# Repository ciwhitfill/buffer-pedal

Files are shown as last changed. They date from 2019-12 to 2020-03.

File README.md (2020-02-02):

# JFET Buffer

This project documents the design and construction of a JFET buffer guitar pedal.

## BOM
|Quantity |Designators |Description |Value |Package |Mouser Part # |
|:---|:---|:---|:---|:---|:---|
|3 |R1, R2, R3  |Resistor |10Mohm, 1/8W  |3.6mm |594-5063JD10M00FT |
|1 |R 5 |Resistor |330ohms, 1/8W |3.6mm |603-MFR-12FTF52-330R|
|1 |R6 |Resistor |100Kohms, 1/8W|3.6mm |603-CFR-12JT-52-100K|
|1 |R7 |Resistor |4.7Kohms, 1/8W|3.6mm |603-MFR-12FTF52-4K7 |
|2 |C1, C2 |Capacitor, polarized|10uF, 16V |4mm |647-USW1C100MDD |
|1 |C3 |Capacitor, polarized|47uF, 25V |5mm |647-UFW1E470MDD |
|2 |Q1, Q2 |N-Channel JFET |J113 |TO-92 |512-J113 |
|1 |D1 |Diode |1N4003 |DO-41 |583-1N4003-T |
|1 |D2 |LED |Green |5mm |859-LTL2R3KGD-EM |
|2 |J1, J2 |Phone Connector |1/4" TS | |568-NYS229 |
|1 |J3 |DC Power Connector  |2.1mm | |163-1060-EX |

## Design

The circuit consists of a JFET source follower with an active load. Compared to passive biasing, an active load provides an operating point that is stable over a much larger range of voltages. This allows the amplifier to drive lower impedance loads at lower supply voltages.

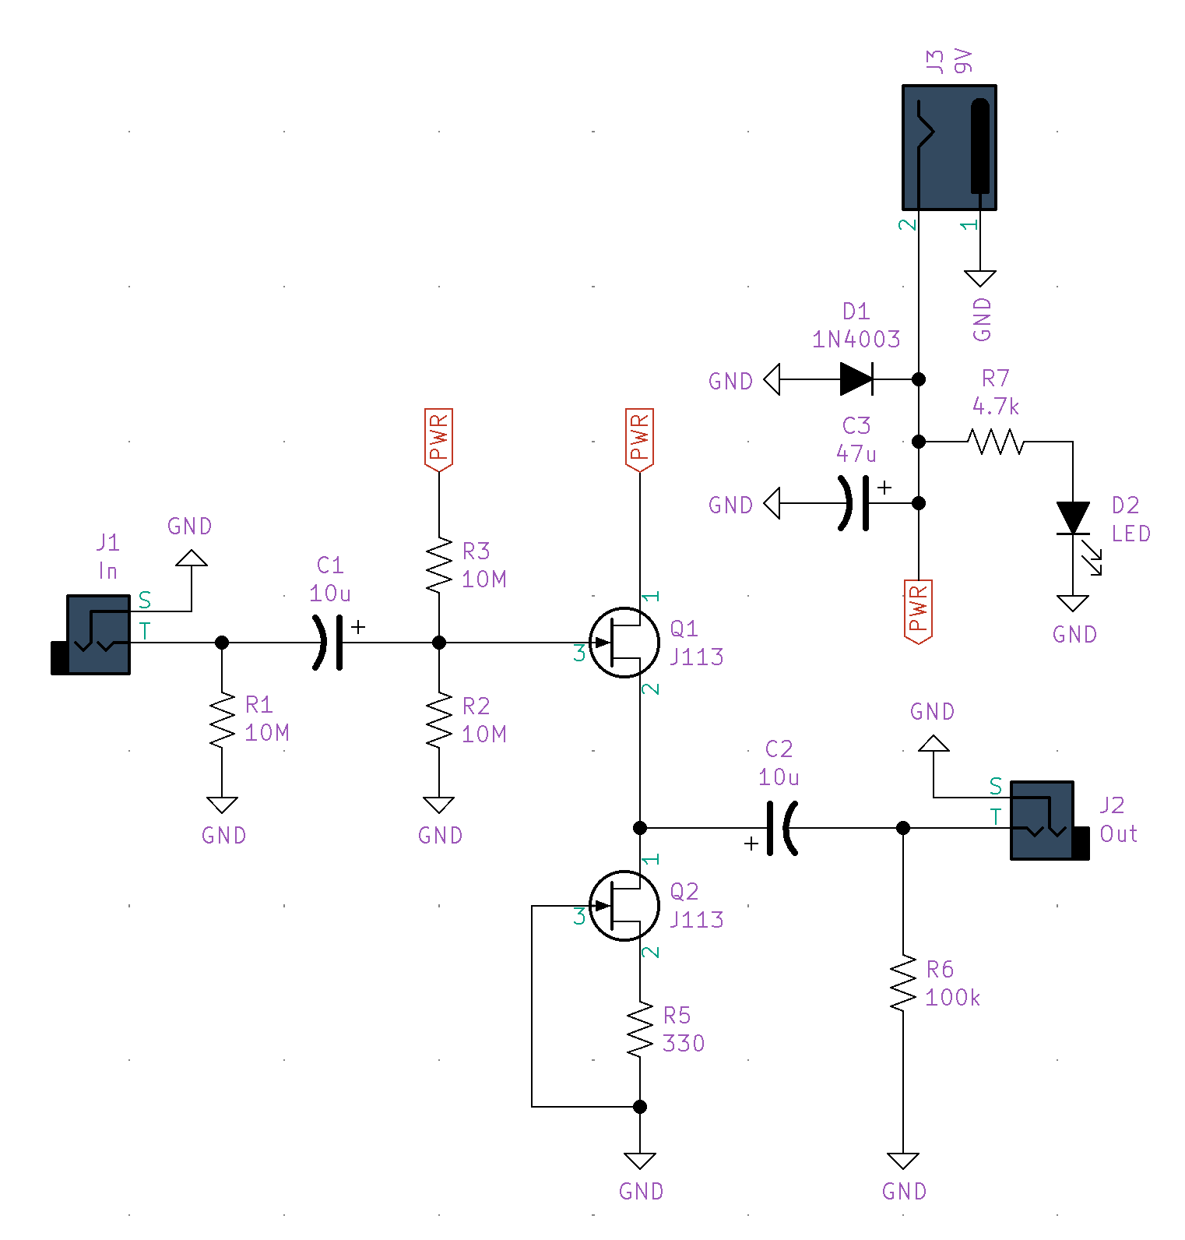
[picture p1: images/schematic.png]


## Simulation Results
The following simulations were conducted in LTspice. For the schematic file and simulation results, [see the simulation folder.](./simulation)

### Input Impedance 
A high input impedance is necessary to avoid loading passive guitar pickups. Generally, an input impedance of at least 1 MΩ is desired. The design provides this impedance throughout the audio range.

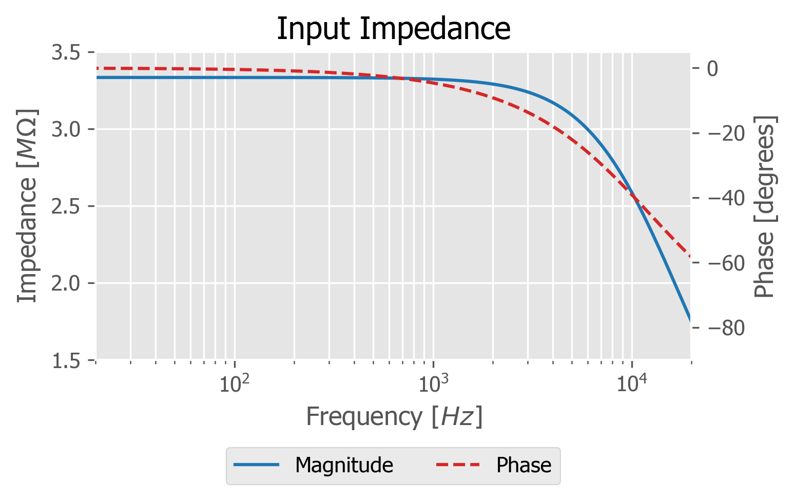
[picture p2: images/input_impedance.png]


### Output Impedance
The design provides a low enough output impedance to drive line-level inputs. While the coupling capacitor dominates at low frequencies, the output impedance asymptotes to 100 Ω, which is more than sufficient for instrument level applications.

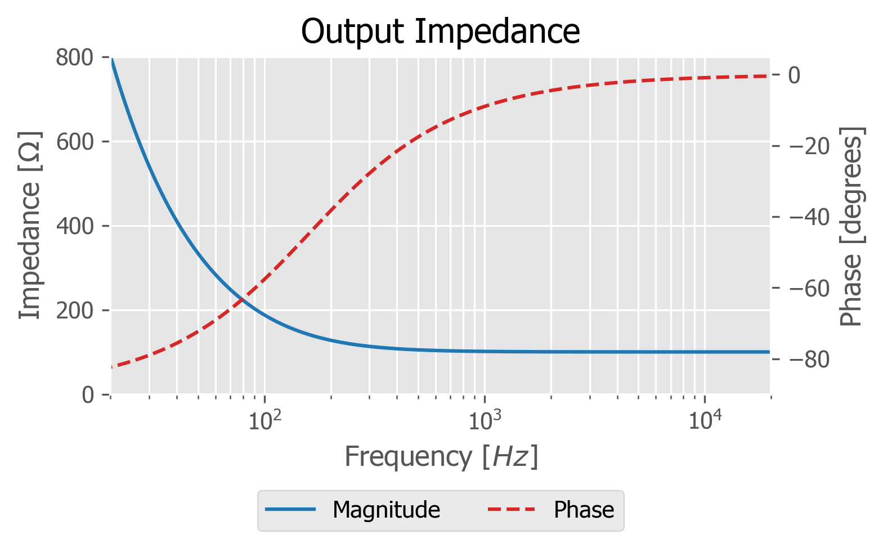
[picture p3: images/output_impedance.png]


### Gain
A good voltage buffer has as close to a gain of 1 as possible. Due to the higher impedance of the active load, the design comes within 0.1 dB of this.

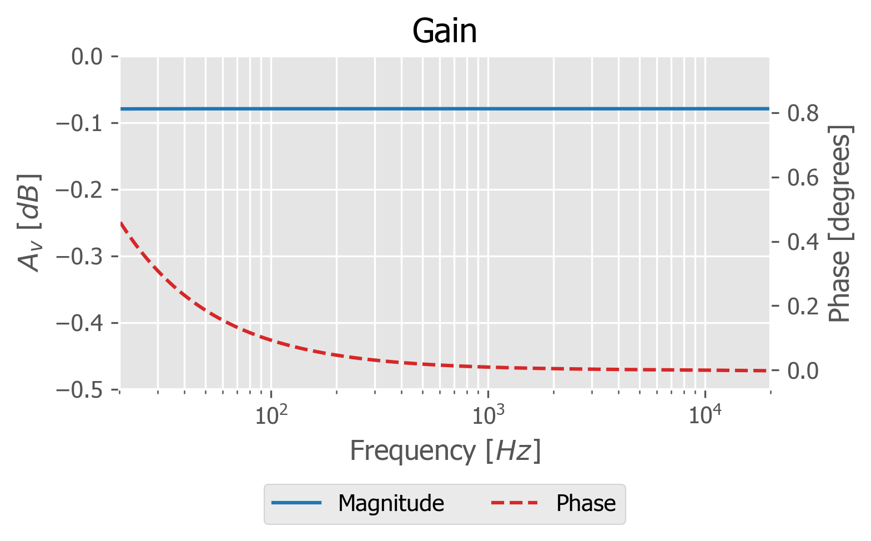
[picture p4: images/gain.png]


### Power Supply Rejection
The design has a PSRR of -43dB at DC, and the power supply capacitor further filters supply noise at high frequencies.

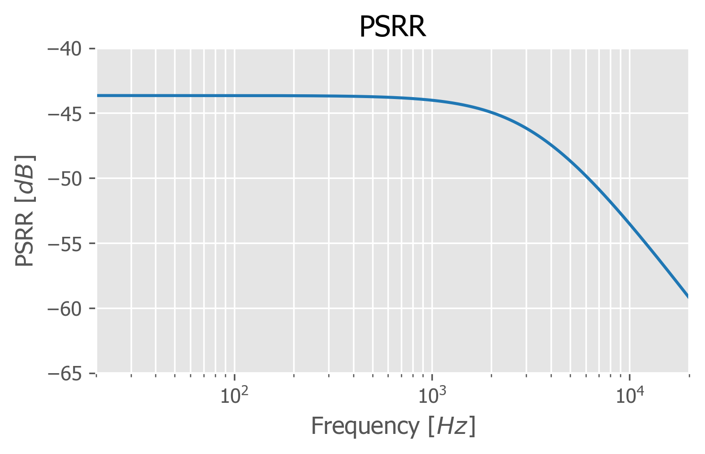
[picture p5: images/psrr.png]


### Noise
Noise simulation results in 171.18 nV in the audio range. Even if actual circuit noise is many times worse, it will be negligible compared to other noise sources in the signal chain.

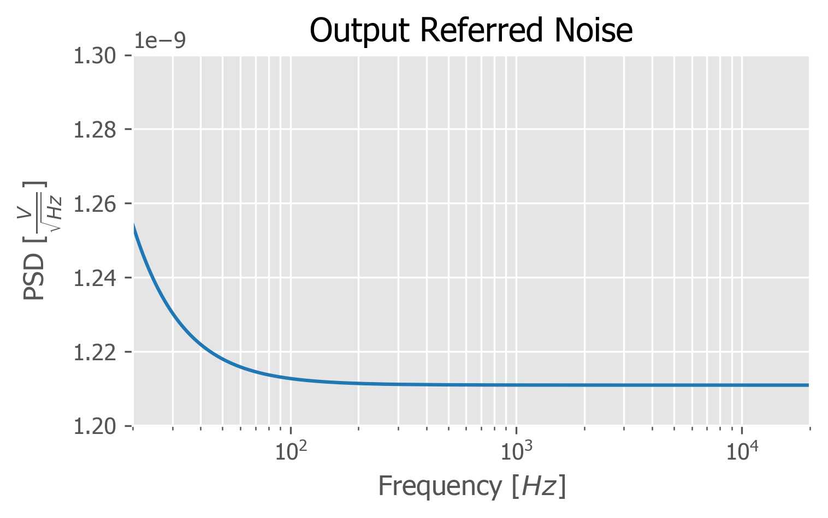
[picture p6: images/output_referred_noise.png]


## Testing

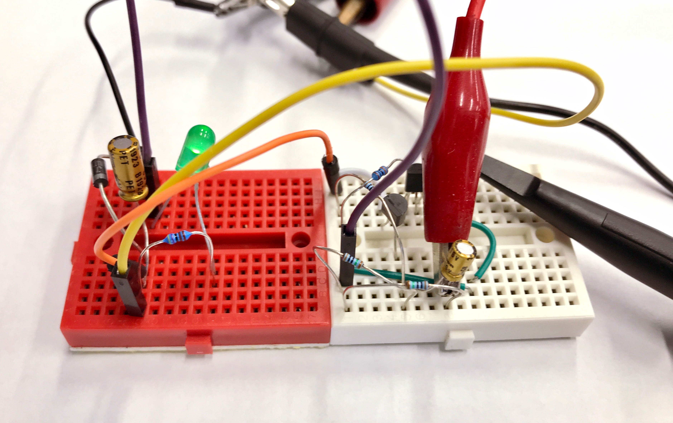
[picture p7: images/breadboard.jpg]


When a 1 V, 1 kHz test signal is applied to the input, the buffer reproduces it at the output within the precision of the test equipment available.

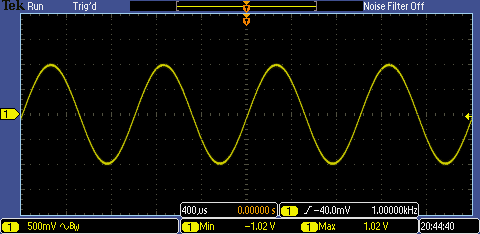
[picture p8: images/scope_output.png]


When overdriven, the buffer clips asymmetically, resulting in predominantly 2nd-order harmonic distortion. In guitar circuits, this is generally preferred to the odd-order distortion of amplifiers with high loop gain.

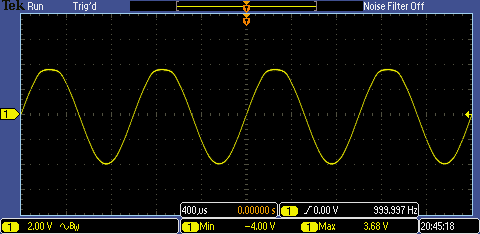
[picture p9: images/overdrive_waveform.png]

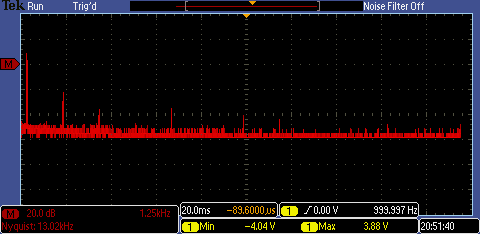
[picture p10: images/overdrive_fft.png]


### Frequency Response
In practice, the amplifier exhibits mild roll-off of sub-bass frequencies below 30 Hz. This is well below the necessary bandwidth of a guitar amplifier. The high-end frequency response extends well above the audio band, ensuring accurate phase response.

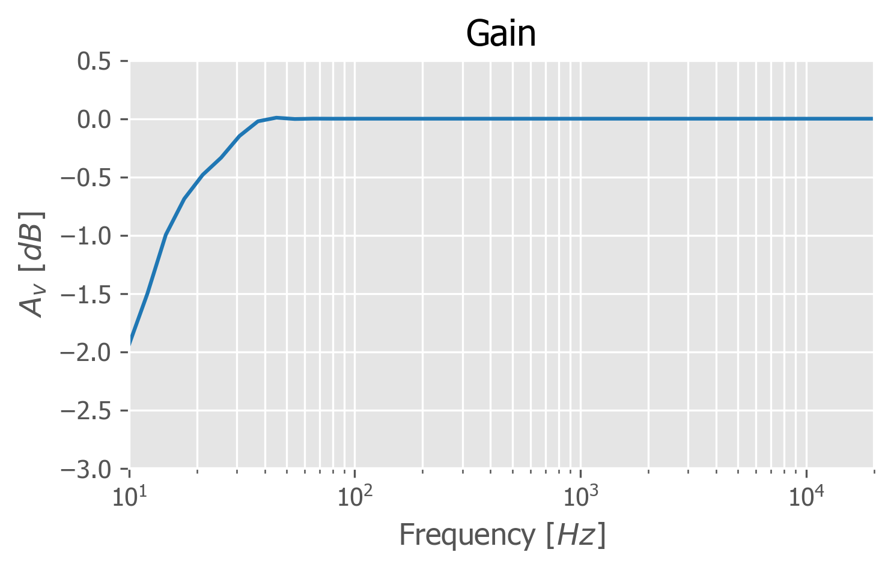
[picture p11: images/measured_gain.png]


## Assembly

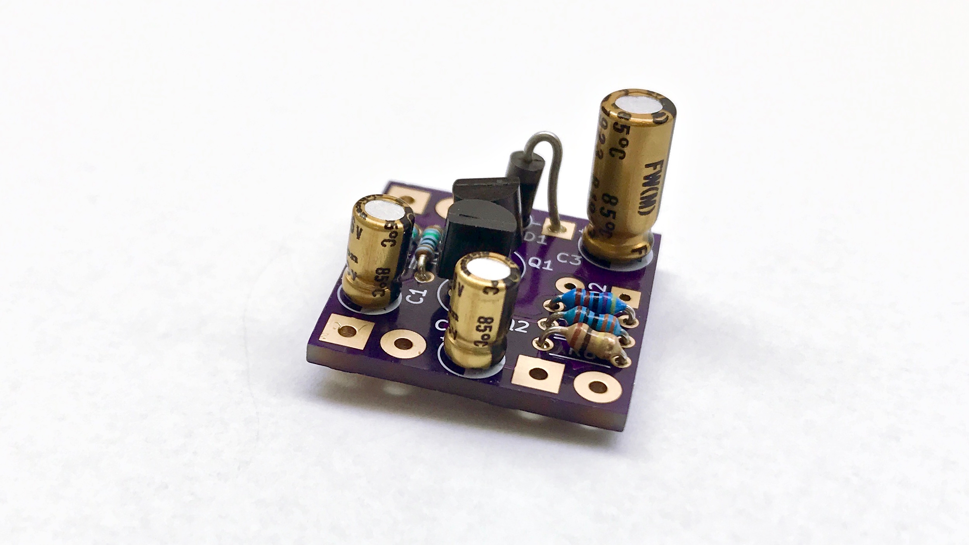
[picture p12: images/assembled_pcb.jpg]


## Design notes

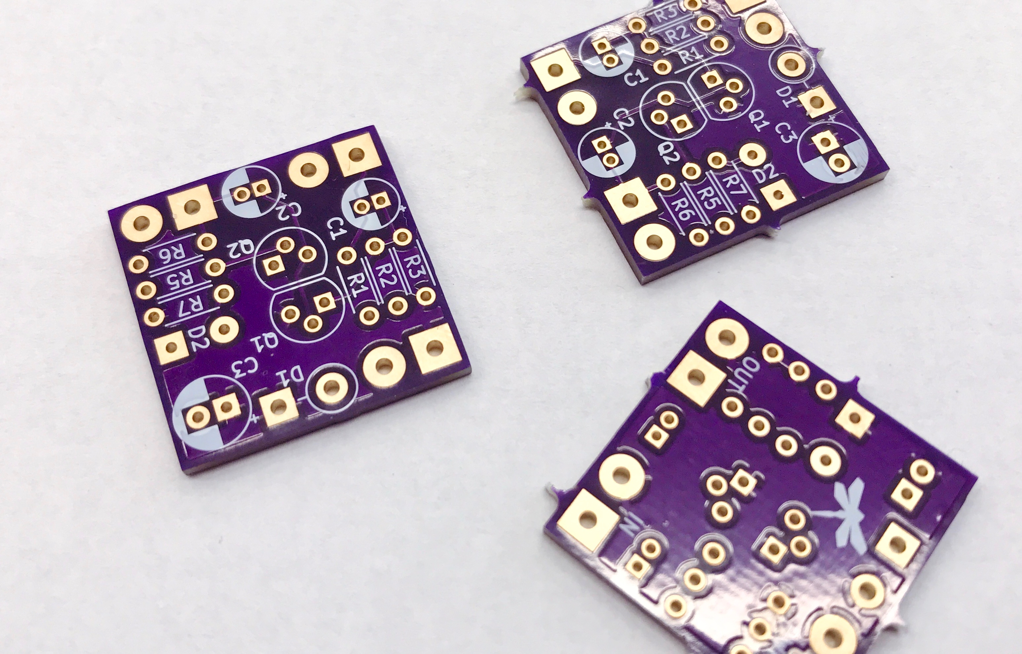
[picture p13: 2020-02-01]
images/pcb.jpg

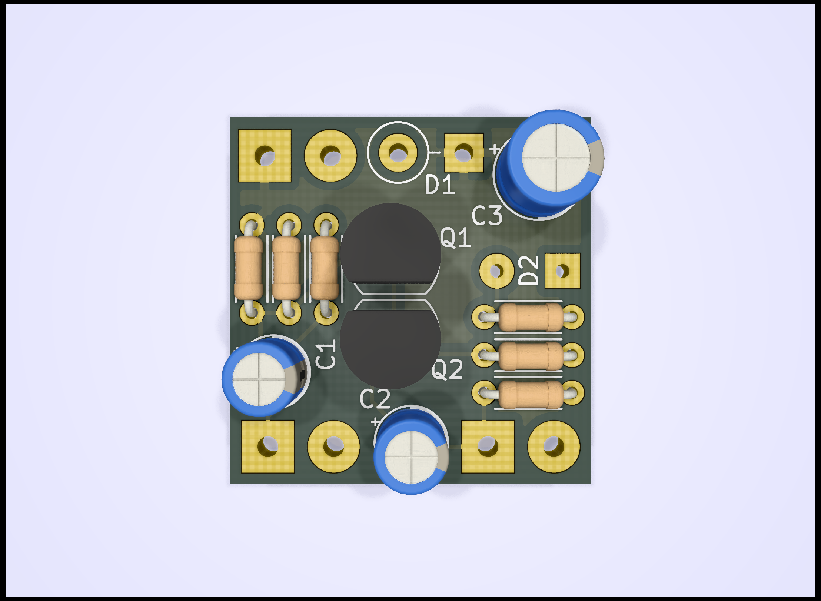
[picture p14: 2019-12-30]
images/pcb_render.png

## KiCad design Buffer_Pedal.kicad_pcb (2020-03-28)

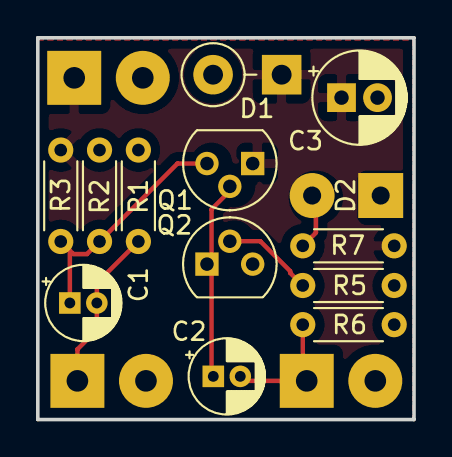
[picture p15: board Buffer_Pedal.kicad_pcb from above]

Board: 2 copper layers, 20.9 x 21.2 mm, 16 parts (0 on the bottom side), 8 nets.

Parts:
C1, C2: 10u; CP_Radial_D4.0mm_P1.50mm
C3: 47u; CP_Radial_D5.0mm_P2.00mm
D1: 1N4003; D_DO-41_SOD81_P3.81mm_Vertical_KathodeUp
D2: LED; SolderWirePad_1x02_P3.81mm_Drill1mm
IN: In; SolderWirePad_1x02_P3.81mm_Drill1.2mm
OUT: Out; SolderWirePad_1x02_P3.81mm_Drill1.2mm
PWR: 9V; SolderWirePad_1x02_P3.81mm_Drill1.2mm
Q1, Q2: J113; TO-92
R1, R2, R3: 10M; R_Axial_DIN0204_L3.6mm_D1.6mm_P5.08mm_Horizontal
R5: 330; R_Axial_DIN0204_L3.6mm_D1.6mm_P5.08mm_Horizontal
R6: 100k; R_Axial_DIN0204_L3.6mm_D1.6mm_P5.08mm_Horizontal
R7: 4.7k; R_Axial_DIN0204_L3.6mm_D1.6mm_P5.08mm_Horizontal

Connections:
GND: C3.2, D1.2, D2.1, IN.2, OUT.2, PWR.2, Q2.3, R1.1, R2.2, R5.2, R6.2
unnamed: C1.1, Q1.3, R2.1, R3.2
unnamed: C1.2, IN.1, R1.2
unnamed: C2.1, Q1.2, Q2.1
unnamed: C2.2, OUT.1, R6.1
unnamed: D2.2, R7.1
unnamed: Q2.2, R5.1
PWR: C3.1, D1.1, PWR.1, Q1.1, R3.1, R7.2

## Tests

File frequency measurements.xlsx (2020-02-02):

Frequency | Amplitude
5 | 0.56
6 | 0.62
7 | 0.68
8 | 0.72
9 | 0.76
10 | 0.8
11 | 0.82
12 | 0.84
13 | 0.86
14 | 0.88
15 | 0.9
17 | 0.92
20 | 0.94
25 | 0.96
30 | 0.98
40 | 1
50 | 1
60 | 1
70 | 1
80 | 1
90 | 1
100 | 1
120 | 1
150 | 1
180 | 1
220 | 1
260 | 1
300 | 1
350 | 1
400 | 1
500 | 1
750 | 1
1000 | 1
1500 | 1
2000 | 1
3000 | 1
4000 | 1
6000 | 1
8000 | 1
10000 | 1
12000 | 1
14000 | 1
16000 | 1
18000 | 1
20000 | 1
25000 | 1
30000 | 1
35000 | 1
40000 | 1
45000 | 1
50000 | 1
60000 | 1
70000 | 1
80000 | 1
90000 | 1
100000 | 1
120000 | 1
150000 | 1
200000 | 1

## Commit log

2019-12-29 Initial Commit 2
    [Buffer_Pedal.kicad_pcb, Buffer_Pedal.sch]
2019-12-29 added schematic image
2019-12-30 added BOM, PCB render
    [BOM.xlsx]
2019-12-30 corrected power jack polarity
    [Buffer_Pedal.sch]
2019-12-30 moved BOM to top of readme
2019-12-31 changed DC power jack in BOM
    metal jack body + center negative = ground short
    [BOM.xlsx]
2020-01-01 fixed JFET pinout
    [Buffer_Pedal.kicad_pcb, Buffer_Pedal.sch]
2020-01-02 updated schematic and layout
    [Buffer_Pedal.kicad_pcb, Buffer_Pedal.sch]
2020-01-02 fixed cursor in schematic image
2020-02-01 lab measurements
    [frequency measurements.xlsx]
2020-02-02 graphed lab measurements
    [frequency measurements.xlsx]
2020-02-02 added lab measurements
    [frequency measurements.xlsx]
2020-02-02 added pcb image
2020-03-28 larger D2 footprint
    [Buffer_Pedal.kicad_pcb]
